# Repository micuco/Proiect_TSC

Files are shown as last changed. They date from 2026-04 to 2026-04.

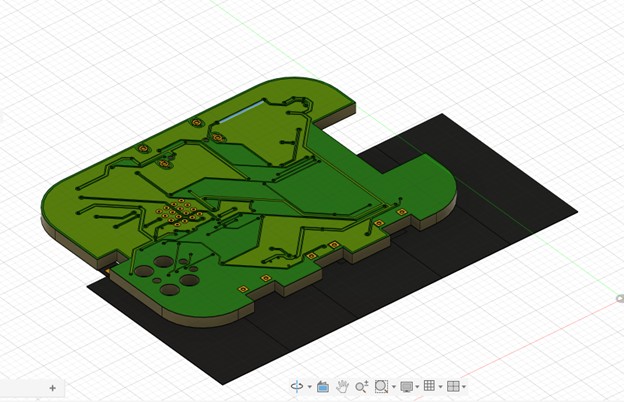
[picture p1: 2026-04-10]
Images/Picture1.jpg

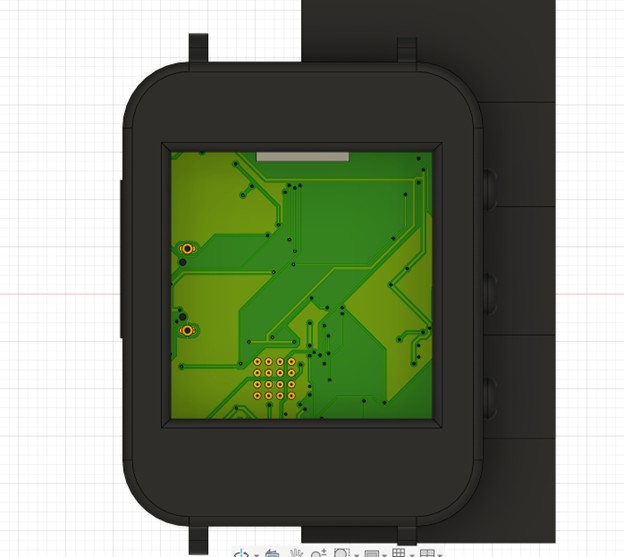
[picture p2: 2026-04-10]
Images/Picture4.jpg

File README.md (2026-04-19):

# Proiect_TSC
InkTime este un smartwatch low-cost, open-source, bazat pe microcontroller-ul nRF52840. Proiectul acopera intreg procesul de dezvoltare hardware, de la schema electrica pana la integrarea mecanica intr-o carcasa.

Sistemul este compus din urmatoarele blocuri principale: MCU nRF52840, Power Management (LiPo Charger + DC/DC), IMU, E-paper Display + Driver, Fuel Gauge, USB-C + ESD Protection, Haptic Driver, Butoane, Interfata SWD.

Microcontroller-ul principal gestioneaza: comunicatia BLE, interfata SPI pentru display, I2C pentru senzori (IMU, fuel gauge),USB pentru alimentare si debug.

Sistemul de alimentare include: BQ25180 pentru incarcarea bateriei LiPo, RT6160 pentru conversie DC/DC, multiple condensatoare de decuplare (100nF, 1uF, 4.7uF). Traseele de alimentare sunt dimensionate conform cerintelor (min 0.3mm).

IMU (BMA421): conectat pe I2C (SDA, SCL), semnale de intrerupere: INT1, INT2, utilizat pentru detectarea miscarii si gesturilor.

E-Paper Display: conectare prin SPI (MOSI, SCK, CS, DC, RST), driver dedicat pentru generarea tensiunilor necesare (boost circuit).

Fuel Gauge: monitorizeaza nivelul bateriei, conectat pe I2C, pin ALERT pentru notificari.

Haptic Driver: DRV2605 pentru control vibratii, control prin I2C, semnal enable din MCU.

USB-C: folosit pentru alimentare si comunicatie, protejat cu circuit ESD dedicat.

Butoane: 3 butoane, conectate la GPIO cu rezistente pull-up/pull-down.

Pin Mapping (nRF52840):

| Functie | Pin |
| --- | --- |
| I2C SDA | P0.xx |
| I2C SCL | P0.xx |
| SPI MOSI | P0.xx |
| SPI SCK | P0.xx |
| EPD CS/DC/RST | GPIO |
| IMU INT | GPIO |
| SWDIO | dedicat |
| SWDCLK | dedicat |

Design Decisions: folosirea e-paper pentru consum redus, integrarea fuel gauge pentru autonomie, antena externa pozitionata la marginea PCB-ului, separarea clara a planurilor de masa.

DRC & ERC: verificari efectuate, respectate regulile de routare, fara unghiuri de 90, condensatoare de decuplare aproape de IC-uri.

PCB Design: PCB 2 layer (TOP + BOTTOM), plan de masa pe ambele layere, via stitching pentru GND, componente plasate pe TOP, trasee: power: ≥ 0.3mm, semnal: ≥ 0.15mm, antena: plasata la marginea PCB, fara plan de masa sub ea.

Modelul 3D include: PCB complet cu componente, baterie LiPo (modelata conform datasheet), display e-paper, carcasa smartwatch.

Integrarea presupune: alinierea butoanelor cu carcasa, pozitionarea corecta a USB-C, fixarea bateriei pe test pads, verificarea spatiului intern si a interferentelor..

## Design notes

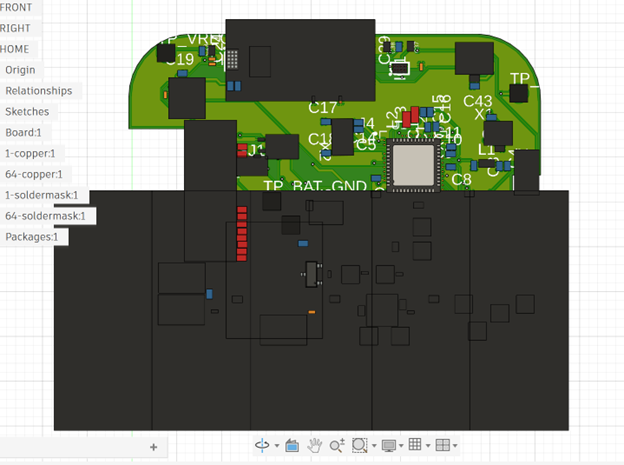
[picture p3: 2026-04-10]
Images/Picture3.png

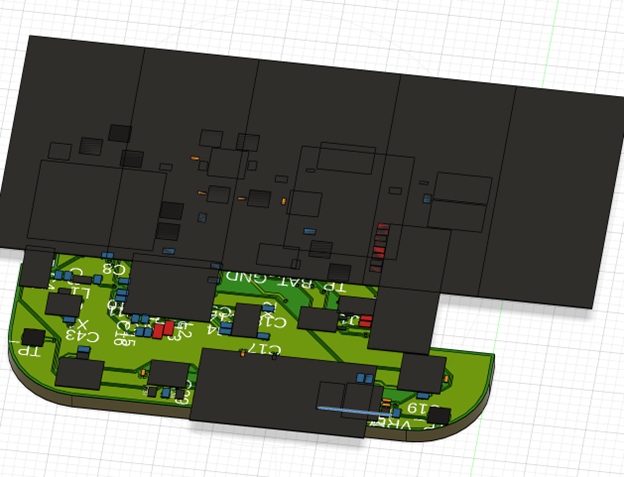
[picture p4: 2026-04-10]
Images/Picture2.png

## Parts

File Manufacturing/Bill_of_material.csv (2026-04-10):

Qty | Value | Device | Package | Parts | Description | ARROW_PART_NUMBER | ARROW_PRICE-STOCK | AVAILABILITY | CHECK_PRICES | COPYRIGHT | DESCRIPTION | DIGI-KEY_PART_NUMBER_1 | DIGI-KEY_PART_NUMBER_2 | DIGI-KEY_PART_NUMBER_3 | HEIGHT | JLCPCB | MANUFACTURER_NAME | MANUFACTURER_PART_NUMBER | MF | MFR_NAME | MOUSER_PART_NUMBER | MOUSER_PRICE-STOCK | MP | PACKAGE | POPULARITY | PRICE | PROD_ID | PURCHASE-URL | SNAPEDA_LINK | TP_SIGNAL_NAME | VALUE
1 |  | ESP32_C6_LIBRARY_7_JUMPER_SJ | ESP32_C6_LIBRARY_7_JUMPER_SJ | SJ1 | SMD solder JUMPER |  |  |  |  |  |  |  |  |  |  |  |  |  |  |  |  |  |  |  | 3
3 | 0 | CPF0201D7K68C1_CPF0201D7K68C1 | CPF0201D7K68C1_0201 | R2, R3, R4 | 7.68k 0201 Thin Film Surface Mount Fixed Resistor +/-0.5% 0.031W CPF0201D7K68C1
4 | 0.1uF | GRM011R60J152KE01L_2_GRM011R60J152KE01L | GRM011R60J152KE01L_2_CAPC0201X13N | C23, C27, C34, C42 | Check availability |  |  | In Stock | https://www.snapeda.com/parts/GRM011R60J152KE01L/Murata/view-part/?ref=eda |  | SMD Capacitor X5R(EIA) with Capacitance: 1500pF Tol. 10%. Rated Voltage: 6.3Vdc |  |  |  |  |  |  |  | Murata |  |  |  | GRM011R60J152KE01L | 0201 Murata |  | None |  |  | https://www.snapeda.com/parts/GRM011R60J152KE01L/Murata/view-part/?ref=snap
1 | 0.1uF/50V | NORDIC_NRF_3_CAPACITOR_0201_L | NORDIC_NRF_3_RESC0201_L | EPD_C5 | Generic chip capacitor
1 | 0.47 | ERA-1AEB3401C_CPF0201D7K68C1 | ERA-1AEB3401C_0201 | R1_EP_DR | 7.68k 0201 Thin Film Surface Mount Fixed Resistor +/-0.5% 0.031W CPF0201D7K68C1
1 | 1.0µF | NORDIC_NRF_3_CAPACITOR_0201_L | NORDIC_NRF_3_RESC0201_L | C15 | Generic chip capacitor
5 | 100nF | NORDIC_NRF_3_CAPACITOR_0201_L | NORDIC_NRF_3_RESC0201_L | C5, C7, C8, C12, C19 | Generic chip capacitor
1 | 100pF | NORDIC_NRF_3_CAPACITOR_0201_L | NORDIC_NRF_3_RESC0201_L | C11 | Generic chip capacitor
5 | 10k | CPF0201D7K68C1_CPF0201D7K68C1 | CPF0201D7K68C1_0201 | R1, R7, R8, R9, R_PWR_EPD | 7.68k 0201 Thin Film Surface Mount Fixed Resistor +/-0.5% 0.031W CPF0201D7K68C1
1 | 10k | ERA-1AEB3401C_CPF0201D7K68C1 | ERA-1AEB3401C_0201 | R2_EP_DR | 7.68k 0201 Thin Film Surface Mount Fixed Resistor +/-0.5% 0.031W CPF0201D7K68C1
3 | 10uF | NORDIC_NRF_3_CAPACITOR_0201_L | NORDIC_NRF_3_RESC0201_L | C1-EP-DR, C24, C39 | Generic chip capacitor
1 | 10µH | NORDIC_NRF_2_INDUCTOR_0402_L | NORDIC_NRF_2_RESC0402_L | L2 | Generic chip inductor
4 | 12pF | NORDIC_NRF_3_CAPACITOR_0201_L | NORDIC_NRF_3_RESC0201_L | C1, C2, C17, C18 | Generic chip capacitor
1 | 15nH | NORDIC_NRF_2_INDUCTOR_0402_L | NORDIC_NRF_2_RESC0402_L | L3 | Generic chip inductor
2 | 1pF | NORDIC_NRF_3_CAPACITOR_0201_L | NORDIC_NRF_3_RESC0201_L | C3, C4 | Generic chip capacitor
6 | 1uF | GRM011R60J152KE01L_2_GRM011R60J152KE01L | GRM011R60J152KE01L_2_CAPC0201X13N | C29, C30, C31, C32, C37, C38 | Check availability |  |  | In Stock | https://www.snapeda.com/parts/GRM011R60J152KE01L/Murata/view-part/?ref=eda |  | SMD Capacitor X5R(EIA) with Capacitance: 1500pF Tol. 10%. Rated Voltage: 6.3Vdc |  |  |  |  |  |  |  | Murata |  |  |  | GRM011R60J152KE01L | 0201 Murata |  | None |  |  | https://www.snapeda.com/parts/GRM011R60J152KE01L/Murata/view-part/?ref=snap
9 | 1uF/50V | NORDIC_NRF_3_CAPACITOR_0201_L | NORDIC_NRF_3_RESC0201_L | EPD_C1, EPD_C2, EPD_C6, EPD_C7, EPD_C8, EPD_C9, EPD_C10, EPD_C11, EPD_C12 | Generic chip capacitor
1 | 2.2 | ERA-1AEB3401C_CPF0201D7K68C1 | ERA-1AEB3401C_0201 | R_TYPE_SEL | 7.68k 0201 Thin Film Surface Mount Fixed Resistor +/-0.5% 0.031W CPF0201D7K68C1
3 | 2025-10-22_07-23-44_LIBRARY_EVP-AKE31ASW_EVP-AKE31A_PAN | 2025-10-22_07-23-44_LIBRARY_EVP-AKE31ASW_EVP-AKE31A_PAN | 2025-10-22_07-23-44_LIBRARY_SW_EVP-AKE31A_PAN | SW_DN, SW_ENT, SW_UP |  |  |  |  |  | Copyright (C) 2025 Ultra Librarian. All rights reserved. |  | P123437TR-ND | P123437CT-ND | P123437DKR-ND |  |  | Panasonic | EVP-AKE31A
1 | 20V/4.2A/52mO/1.4W | ESP32_C6_LIBRARY_4_ESP32_WROVER_SPARKFUN-DISCRETESEMI_MOSFET_PCH-DMG2305UX-7 | ESP32_C6_LIBRARY_4_ESP32_C6_LIBRARY_4_ESP32_C6_LIBRARY_4_ESP32_C6_LIBRARY_4_ESP32_WROVER_SPARKFUN-DISCRETESEMI_SOT23-3 | Q1 | P-channel MOSFETs |  |  |  |  |  |  |  |  |  |  |  |  |  |  |  |  |  |  |  |  |  | TRAN-14388 |  |  |  | 20V/4.2A/52mO/1.4W
2 | 22uF | NORDIC_NRF_3_CAPACITOR_0201_L | NORDIC_NRF_3_RESC0201_L | C25, C33 | Generic chip capacitor
1 | 2450AT18B100E | 2450AT18B100E_2450AT18B100E | 2450AT18B100E_ANTC3216X140N | ANT1 | Antennas 2.45GHz ANTENNA | 2450AT18B100E | https://www.arrow.com/en/products/2450at18b100e/johanson-dielectrics?utm_currency=USD&region=nac |  |  |  | Antennas 2.45GHz ANTENNA |  |  |  | 1.4mm |  | JOHANSON TECHNOLOGY | 2450AT18B100E |  |  | 609-2450AT18B100E | https://www.mouser.co.uk/ProductDetail/Johanson-Technology/2450AT18B100E?qs=yCnrNFeXz%252Bh5MFsFIXGZGA%3D%3D
1 | 3.9nH | NORDIC_NRF_2_INDUCTOR_0402_L | NORDIC_NRF_2_RESC0402_L | L1 | Generic chip inductor
1 | 32.768kHz | NORDIC_NRF_1_XTAL_32KHZ | NORDIC_NRF_1_XTAL_3215_N | X2
1 | 32MHz | NORDIC_NRF_XTAL_32MHZ | NORDIC_NRF_BT-XTAL_2016_N | X1
2 | 3K3 | CPF0201D7K68C1_CPF0201D7K68C1 | CPF0201D7K68C1_0201 | R17, R18 | 7.68k 0201 Thin Film Surface Mount Fixed Resistor +/-0.5% 0.031W CPF0201D7K68C1
1 | 4.7uF | NORDIC_NRF_3_CAPACITOR_0201_L | NORDIC_NRF_3_RESC0201_L | C43 | Generic chip capacitor
1 | 4.7uF/25V | NORDIC_NRF_3_CAPACITOR_0201_L | NORDIC_NRF_3_RESC0201_L | C2-EP-DR | Generic chip capacitor
4 | 4.7µF | NORDIC_NRF_3_CAPACITOR_0201_L | NORDIC_NRF_3_RESC0201_L | C6, C14, C20, C21 | Generic chip capacitor
1 | 47nF | NORDIC_NRF_3_CAPACITOR_0201_L | NORDIC_NRF_3_RESC0201_L | C16 | Generic chip capacitor
1 | 503480-2400 | 503480-2400_503480-2400 | 503480-2400_5034802400 | J1 | FFC & FPC Connectors 0.5mm FPC RA SMT Dual Contact 24Ckt |  |  |  |  |  | FFC & FPC Connectors 0.5mm FPC RA SMT Dual Contact 24Ckt |  |  |  | 1.87mm |  | Molex | 503480-2400 |  |  | 538-503480-2400 | https://www.mouser.co.uk/ProductDetail/Molex/503480-2400?qs=OAhjpuo3Vu7efIoxFh9AOw%3D%3D
1 | 5K1 | CPF0201D7K68C1_CPF0201D7K68C1 | CPF0201D7K68C1_0201 | R1_USB | 7.68k 0201 Thin Film Surface Mount Fixed Resistor +/-0.5% 0.031W CPF0201D7K68C1
1 | 5K1 | ERA-1AEB3401C_CPF0201D7K68C1 | ERA-1AEB3401C_0201 | R2_USB | 7.68k 0201 Thin Film Surface Mount Fixed Resistor +/-0.5% 0.031W CPF0201D7K68C1
1 | 68uH | ESP32_C6_LIBRARY_2_744043680IND_4828-WE-TPC_WRE | ESP32_C6_LIBRARY_2_IND_4828-WE-TPC_WRE | L5 |  |  |  |  |  | Copyright (C) 2024 Ultra Librarian. All rights reserved. |  |  |  |  |  |  |  | 744043680 |  | Wurth Electronics
1 | 820pF | NORDIC_NRF_3_CAPACITOR_0201_L | NORDIC_NRF_3_RESC0201_L | C9 | Generic chip capacitor
1 | BMA421 | BMA423_BMA423 | BMA423_BMA423 | IC3 | Accelerometers Triaxial low-g 12bit Acceleration Sensor | BMA423 | https://www.arrow.com/en/products/bma423/bosch |  |  |  | Accelerometers Triaxial low-g 12bit Acceleration Sensor |  |  |  | 1mm |  | BOSCH | BMA423 |  |  | 262-BMA423 | https://www.mouser.co.uk/ProductDetail/Bosch-Sensortec/BMA423?qs=HXFqYaX1Q2xC%252BSgeGoX3mg%3D%3D
1 | BQ25180YBGR | BQ25180YBGR_BQ25180YBGR | BQ25180YBGR_BGA8C40P2X4_100X155X50 | IC1 | Charger IC Lithium Ion/Polymer, Lithium Iron Phosphate 8-DSBGA (1.6x1.1) | BQ25180YBGR | https://www.arrow.com/en/products/bq25180ybgr/texas-instruments?utm_currency=USD&region=nac |  |  |  | Charger IC Lithium Ion/Polymer | Lithium Iron Phosphate 8-DSBGA (1.6x1.1) |  |  |  | 0.5mm |  | Texas Instruments | BQ25180YBGR |  |  | 595-BQ25180YBGR | https://www.mouser.co.uk/ProductDetail/Texas-Instruments/BQ25180YBGR?qs=doiCPypUmgEWjAK%252BJAX6Tw%3D%3D
1 | DRV2605YZFR | DRV2605YZFR_DRV2605YZFR | DRV2605YZFR_BGA9C50P3X3_144X144X62 | IC2 | Haptic Driver for ERM/LRA with Built-In Library and Smart Loop Architecture | DRV2605YZFR | https://www.arrow.com/en/products/drv2605yzfr/texas-instruments?region=nac |  |  |  | Haptic Driver for ERM/LRA with Built-In Library and Smart Loop Architecture |  |  |  | 0.625mm |  | Texas Instruments | DRV2605YZFR
1 | FTC252012SR47MBCA | MLP2016SR47MT0S1_FTC252012SR47MBCA | MLP2016SR47MT0S1_INDC2016X100N | L7 | SMD / SMT Inductors (Coils), L=0.47?H, L x W x T : |  |  |  |  |  | SMD / SMT Inductors (Coils) | L=0.47?H | L x W x T : |  |  |  | 1mm | https://jlcpcb.com/partdetail/6763488-FTC252012SR47MBCA/C5832368 | TDK | FTC252012SR47MBCA
14 | HECTOR_WATCH_1_TPTP20R | HECTOR_WATCH_1_TPTP20R | HECTOR_WATCH_1_TP20R | TP_3.3V, TP_3V3, TP_BAT_GND, TP_GND, TP_ON, TP_OP, TP_RESET, TP_SCL, TP_SDA, TP_SWDCLK, TP_SWDIO, TP_SWO, TP_VBAT, TP_VREG | Test pad |  |  |  |  |  |  |  |  |  |  |  |  |  |  |  |  |  |  |  | 2
1 | KH-TYPE-C-16P | KH-TYPE-C-16P_KH-TYPE-C-16P | KH-TYPE-C-16P_KINGHELM_KH-TYPE-C-16P | J4 | Check availability |  |  | Not in stock | https://www.snapeda.com/parts/KH-TYPE-C-16P/Kinghelm/view-part/?ref=eda |  |  |  |  |  |  |  |  |  | kinghelm |  |  |  | KH-TYPE-C-16P | None |  | None |  |  | https://www.snapeda.com/parts/KH-TYPE-C-16P/Kinghelm/view-part/?ref=snap
1 | MAX17048G+T10 | ESP32_C6_LIBRARY_MAX17048G+T10 | ESP32_C6_LIBRARY_SON50P200X200X80-9N | U3 | Check availability |  |  | In Stock | https://www.snapeda.com/parts/MAX17048G+T10/Analog+Devices/view-part/?ref=eda |  | 3µA 1-Cell/2-Cell Fuel Gauge with ModelGauge |  |  |  |  |  |  |  | Analog Devices |  |  |  | MAX17048G+T10 | TDFN-8 Maxim |  | None |  | https://www.snapeda.com/api/url_track_click_mouser/?unipart_id=329239&manufacturer=Analog Devices&part_name=MAX17048G+T10&search_term=None | https://www.snapeda.com/parts/MAX17048G+T10/Analog+Devices/view-part/?ref=snap
3 | MBR0530 | ESP32_C6_LIBRARY_5_MBR0530 | ESP32_C6_LIBRARY_5_SOD3716X135N | D2, D4, D5 | ON SEMICONDUCTOR - MBR0530 - DIODE, SCHOTTKY, 0.5A, 30V, SOD-123 |  |  | In Stock | https://www.snapeda.com/parts/MBR0530/Onsemi/view-part/?ref=eda |  | Diode Schottky 30 V 500mA Surface Mount SOD-123 |  |  |  |  |  |  |  | ON Semiconductor |  |  |  | MBR0530 | SOD-123-2 ON Semiconductor |  | None |  | https://www.snapeda.com/api/url_track_click_mouser/?unipart_id=179458&manufacturer=ON Semiconductor&part_name=MBR0530&search_term=None | https://www.snapeda.com/parts/MBR0530/Onsemi/view-part/?ref=snap
3 | N.C. | NORDIC_NRF_3_CAPACITOR_0201_L | NORDIC_NRF_3_RESC0201_L | C10, C13, C22 | Generic chip capacitor
1 | NRF52840_QF | NORDIC_NRF_4_NRF52840_QF | NORDIC_NRF_4_AQFN50P700X700X85_HS-74N | U1 | nRF52840
1 | RT6160AWSC | RT6160AWSC_RT6160AWSC | RT6160AWSC_BGA15C40P3X5_140X230X60 | IC9 | Buck-Boost Regulator Positive Output Step-Up/Step-Down I2C DC-DC Controller IC 15-WL-CSP (BSC) (1.4x2.3) |  |  |  |  |  | Buck-Boost Regulator Positive Output Step-Up/Step-Down I2C DC-DC Controller IC 15-WL-CSP (BSC) (1.4x2.3) |  |  |  | 0.6mm |  | RICHTEK | RT6160AWSC |  |  | 835-RT6160AWSC | https://www.mouser.co.uk/ProductDetail/Richtek/RT6160AWSC?qs=amGC7iS6iy%2FLd9PSoixZXQ%3D%3D
1 | SI1308EDL-T1-GE3 | ESP32_C6_LIBRARY_6_SI1308EDL-T1-GE3 | ESP32_C6_LIBRARY_6_SOT65P210X110-3N | Q3 | MOSFET N-Ch 30V 1.5A TrenchFET SC70 Vishay Si1308EDL-T1-GE3 N-channel MOSFET Transistor, 1.5 A, 30 V, 3-Pin SC-70 |  |  | In Stock | https://www.snapeda.com/parts/SI1308EDL-T1-GE3/Vishay+Siliconix/view-part/?ref=eda |  | Si1308EDL-T1-GE3 N-channel MOSFET Transistor | 1.5 A | 30 V | 3-Pin SC-70 | Siliconix / Vishay SI1308EDL-T1-GE3 |  |  |  |  |  |  |  | Vishay Siliconix |  |  |  | SI1308EDL-T1-GE3 | SOT-323 Vishay Semiconductor |  | None |  | https://www.snapeda.com/api/url_track_click_mouser/?unipart_id=274603&manufacturer=Vishay Siliconix&part_name=SI1308EDL-T1-GE3&search_term=None
1 | TC2030-IDC | TC2030-IDC_TC2030-IDC | TC2030-IDC_TC2030IDC | J2 | CABLE ADAPTER 6 POS |  |  |  |  |  | CABLE ADAPTER 6 POS |  |  |  | 19mm |  | Tag Connect | TC2030-IDC
1 | USBLC6-2SC6Y | ESP32_C6_LIBRARY_3_USBLC6-2SC6Y | ESP32_C6_LIBRARY_3_SOT95P280X145-6N | D3 | Low Cap. ESD Protection Auto SOT-23-6 STMicroelectronics USBLC6-2SC6Y, Dual Uni-Directional TVS Diode Array, 6-Pin SOT-23 |  |  | In Stock | https://www.snapeda.com/parts/USBLC6-2SC6Y/STMicroelectronics/view-part/?ref=eda |  | 17V Clamp 5A (8/20µs) Ipp Tvs Diode Surface Mount SOT-23-6 |  |  |  |  |  |  |  | STMicroelectronics |  |  |  | USBLC6-2SC6Y | SOT-23-6 STMicroelectronics |  | None |  |  | https://www.snapeda.com/parts/USBLC6-2SC6Y/STMicroelectronics/view-part/?ref=snap

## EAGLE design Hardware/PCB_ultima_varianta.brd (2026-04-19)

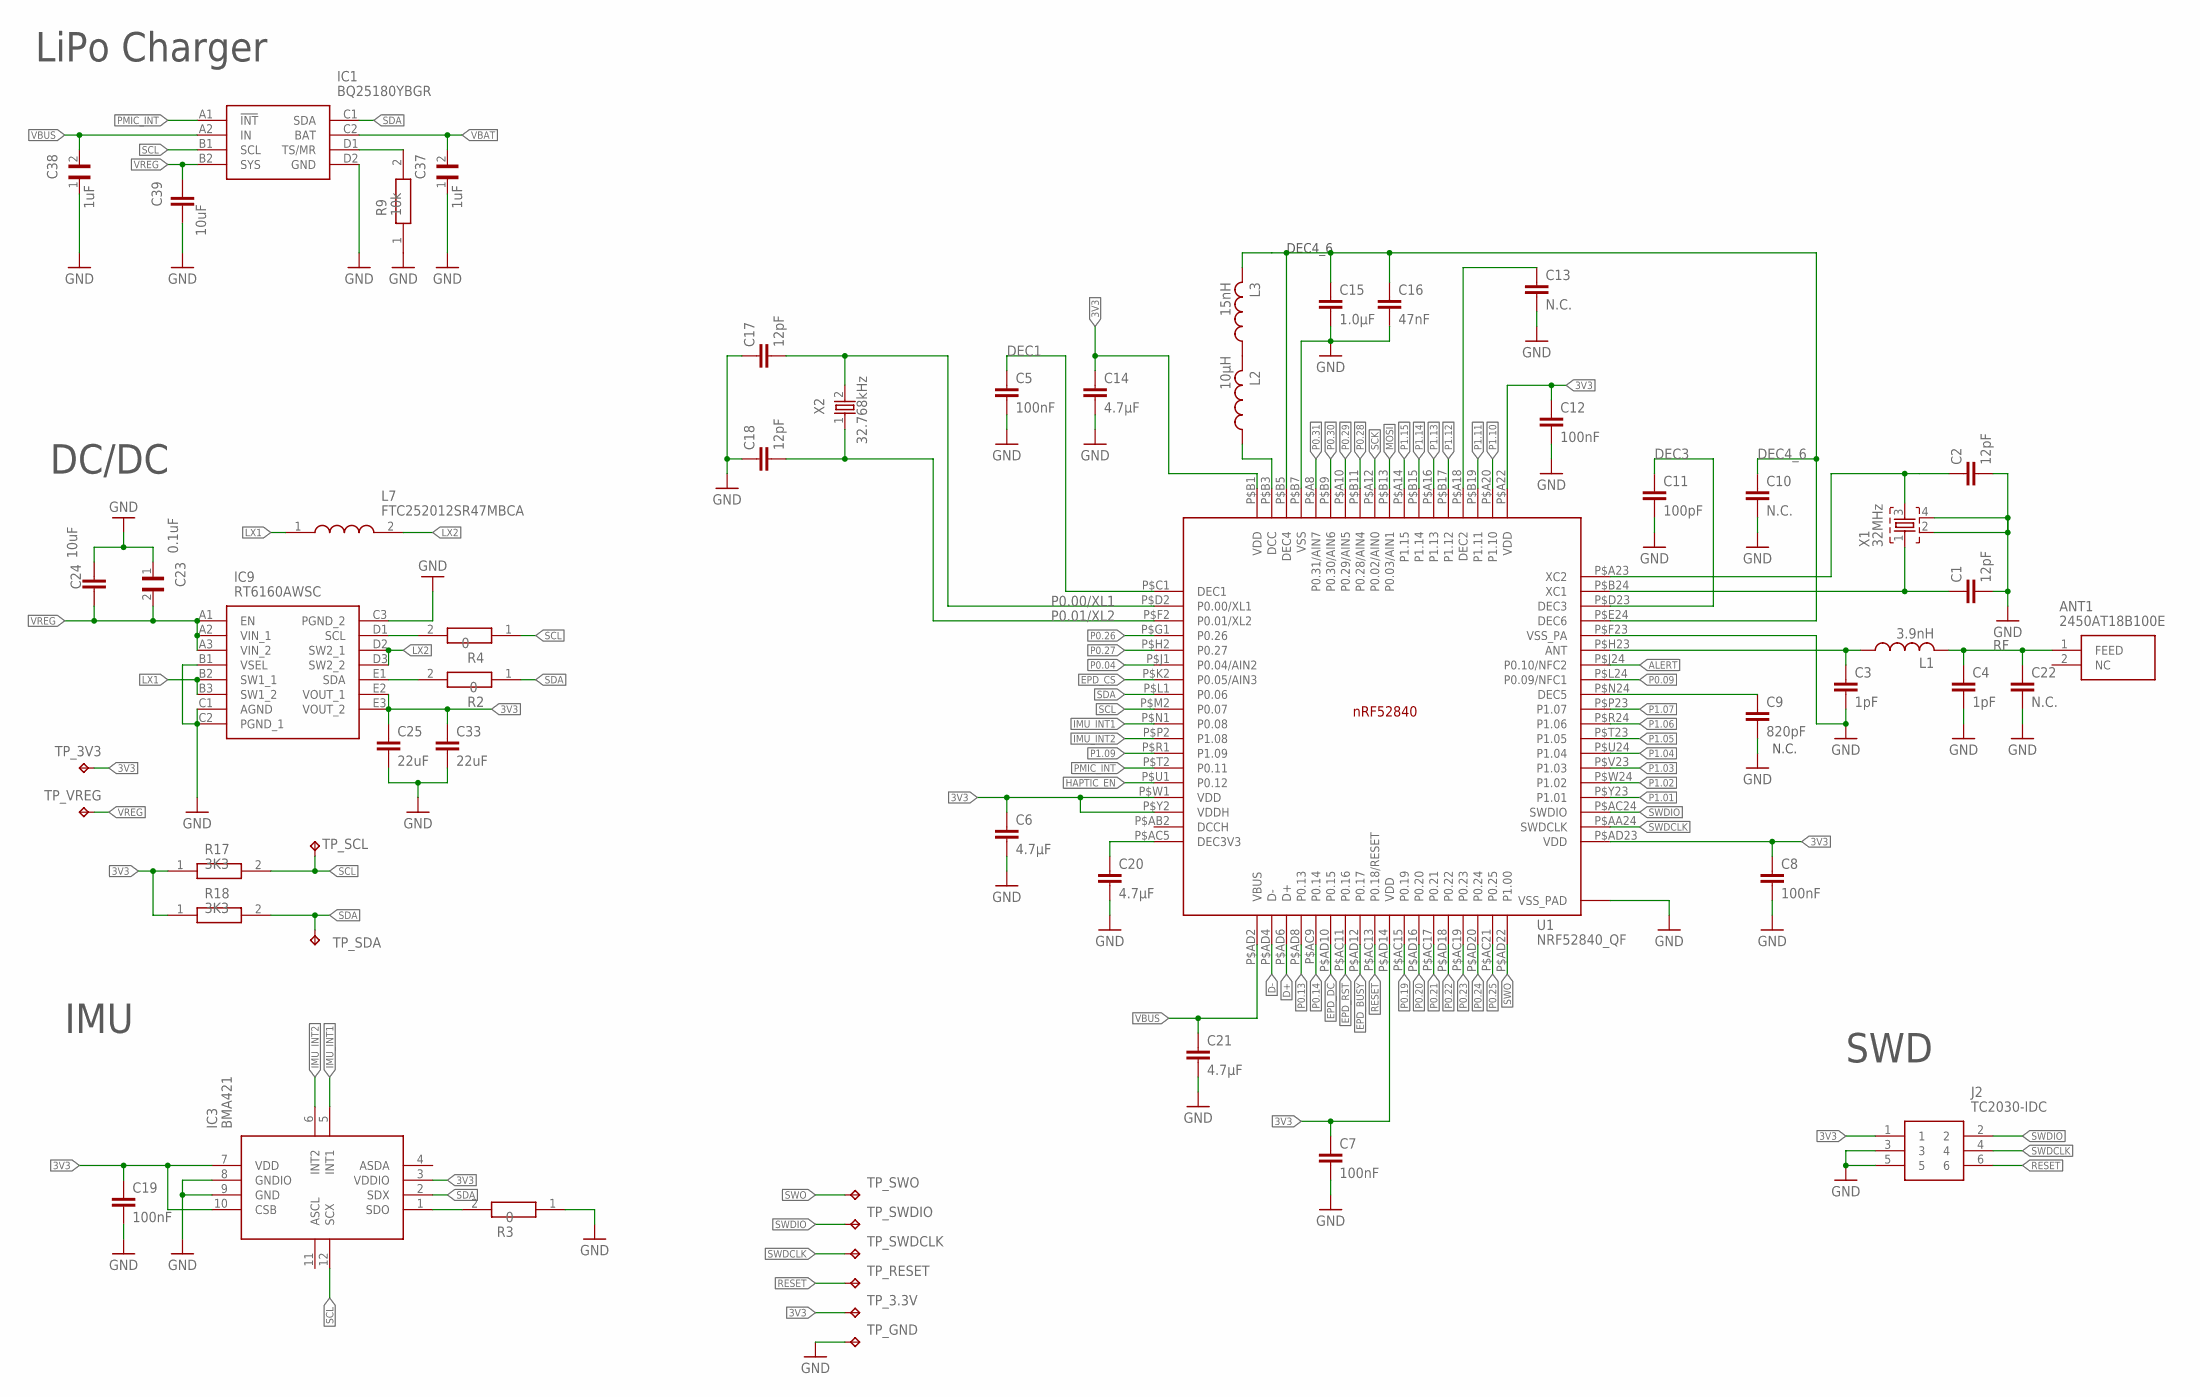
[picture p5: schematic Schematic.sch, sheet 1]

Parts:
ANT1: 2450AT18B100E; 2450AT18B100E_ANTC3216X140N
C1, C2, C17, C18: 12pF; NORDIC_NRF_3_RESC0201_L
C3, C4: 1pF; NORDIC_NRF_3_RESC0201_L
C5, C7, C8, C12, C19: 100nF; NORDIC_NRF_3_RESC0201_L
C6, C14, C20, C21: 4.7µF; NORDIC_NRF_3_RESC0201_L
C9: 820pF; NORDIC_NRF_3_RESC0201_L
C10, C13, C22: N.C.; NORDIC_NRF_3_RESC0201_L
C11: 100pF; NORDIC_NRF_3_RESC0201_L
C15: 1.0µF; NORDIC_NRF_3_RESC0201_L
C16: 47nF; NORDIC_NRF_3_RESC0201_L
C23: 0.1uF; GRM011R60J152KE01L_2_CAPC0201X13N
C24, C39: 10uF; NORDIC_NRF_3_RESC0201_L
C25, C33: 22uF; NORDIC_NRF_3_RESC0201_L
C37, C38: 1uF; GRM011R60J152KE01L_2_CAPC0201X13N
IC1: BQ25180YBGR; BQ25180YBGR_BGA8C40P2X4_100X155X50
IC3: BMA421; BMA423_BMA423
IC9: RT6160AWSC; RT6160AWSC_BGA15C40P3X5_140X230X60
J2: TC2030-IDC; TC2030-IDC_TC2030IDC
L1: 3.9nH; NORDIC_NRF_2_RESC0402_L
L2: 10µH; NORDIC_NRF_2_RESC0402_L
L3: 15nH; NORDIC_NRF_2_RESC0402_L
L7: FTC252012SR47MBCA; MLP2016SR47MT0S1_INDC2016X100N
R2, R3, R4: 0; CPF0201D7K68C1_0201
R9: 10k; CPF0201D7K68C1_0201
R17, R18: 3K3; CPF0201D7K68C1_0201
TP_3.3V, TP_3V3: HECTOR_WATCH_1_TPTP20R; HECTOR_WATCH_1_TP20R
TP_GND: HECTOR_WATCH_1_TPTP20R; HECTOR_WATCH_1_TP20R
TP_RESET: HECTOR_WATCH_1_TPTP20R; HECTOR_WATCH_1_TP20R
TP_SCL: HECTOR_WATCH_1_TPTP20R; HECTOR_WATCH_1_TP20R
TP_SDA: HECTOR_WATCH_1_TPTP20R; HECTOR_WATCH_1_TP20R
TP_SWDCLK: HECTOR_WATCH_1_TPTP20R; HECTOR_WATCH_1_TP20R
TP_SWDIO: HECTOR_WATCH_1_TPTP20R; HECTOR_WATCH_1_TP20R
TP_SWO: HECTOR_WATCH_1_TPTP20R; HECTOR_WATCH_1_TP20R
TP_VREG: HECTOR_WATCH_1_TPTP20R; HECTOR_WATCH_1_TP20R
U1: NRF52840_QF; NORDIC_NRF_4_AQFN50P700X700X85_HS-74N
X1: 32MHz; NORDIC_NRF_BT-XTAL_2016_N
X2: 32.768kHz; NORDIC_NRF_1_XTAL_3215_N

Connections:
3V3: C6.1, C7.1, C8.1, C12.1, C14.1, C19.1, C25.1, C33.1, IC3.3 (VDDIO), IC3.7 (VDD), IC3.10 (CSB), IC9.E2 (VOUT_1), IC9.E3 (VOUT_2), J2.1, R17.1, R18.1, TP_3.3V.TP, TP_3V3.TP, U1.P$A22 (VDD), U1.P$AD14 (VDD), U1.P$AD23 (VDD), U1.P$B1 (VDD), U1.P$W1 (VDD), U1.P$Y2 (VDDH); also elsewhere on the board
ALERT: U1.P$J24 (P0.10/NFC2); also elsewhere on the board
D+: U1.P$AD6 (D+); also elsewhere on the board
D-: U1.P$AD4 (D-); also elsewhere on the board
DEC1: C5.1, U1.P$C1 (DEC1)
DEC3: C11.1, U1.P$D23 (DEC3)
DEC4_6: C10.1, C15.1, C16.1, L3.2, U1.P$B5 (DEC4), U1.P$E24 (DEC6)
EPD_BUSY: U1.P$AD12 (P0.17); also elsewhere on the board
EPD_CS: U1.P$K2 (P0.05/AIN3); also elsewhere on the board
EPD_DC: U1.P$AD10 (P0.15); also elsewhere on the board
EPD_RST: U1.P$AC11 (P0.16); also elsewhere on the board
GND: C1.2, C2.2, C3.2, C4.2, C5.2, C6.2, C7.2, C8.2, C9.2, C10.2, C11.2, C12.2, C13.2, C14.2, C15.2, C16.2, C17.1, C18.1, C19.2, C20.2, C21.2, C22.2, C23.1, C24.2, C25.2, C33.2, C37.1, C38.1, C39.2, IC1.D2 (GND), IC3.8 (GNDIO), IC3.9 (GND), IC9.B1 (VSEL), IC9.C1 (AGND), IC9.C2 (PGND_1), IC9.C3 (PGND_2), J2.3, J2.5, R3.1, R9.1, TP_GND.TP, U1.P$74 (VSS_PAD), U1.P$75 (VSS_PAD), U1.P$76 (VSS_PAD), U1.P$77 (VSS_PAD), U1.P$78 (VSS_PAD), U1.P$79 (VSS_PAD), U1.P$80 (VSS_PAD), U1.P$81 (VSS_PAD), U1.P$82 (VSS_PAD), U1.P$83 (VSS_PAD), U1.P$84 (VSS_PAD), U1.P$85 (VSS_PAD), U1.P$86 (VSS_PAD), U1.P$87 (VSS_PAD), U1.P$88 (VSS_PAD), U1.P$89 (VSS_PAD), U1.P$90 (VSS_PAD), U1.P$B7 (VSS), U1.P$F23 (VSS_PA), X1.2, X1.4; also elsewhere on the board
HAPTIC_EN: U1.P$U1 (P0.12); also elsewhere on the board
IMU_INT1: IC3.5 (INT1), U1.P$N1 (P0.08)
IMU_INT2: IC3.6 (INT2), U1.P$P2 (P1.08)
LX1: IC9.B2 (SW1_1), IC9.B3 (SW1_2), L7.1
LX2: IC9.D2 (SW2_1), IC9.D3 (SW2_2), L7.2
MOSI: U1.P$B13 (P0.03/AIN1); also elsewhere on the board
unnamed: IC1.D1 (TS/MR), R9.2
unnamed: IC3.1 (SDO), R3.2
unnamed: C13.1, U1.P$A18 (DEC2)
unnamed: IC9.D1 (SCL), R4.2
unnamed: IC9.E1 (SDA), R2.2
unnamed: C9.1, U1.P$N24 (DEC5)
unnamed: C20.1, U1.P$AC5 (DEC3V3)
unnamed: L2.2, L3.1
unnamed: L2.1, U1.P$B3 (DCC)
unnamed: C3.1, L1.1, U1.P$H23 (ANT)
unnamed: C1.1, U1.P$B24 (XC1), X1.1
unnamed: C2.1, U1.P$A23 (XC2), X1.3
P0.00/XL1: C17.2, U1.P$D2 (P0.00/XL1), X2.2
P0.01/XL2: C18.2, U1.P$F2 (P0.01/XL2), X2.1
P0.04: U1.P$J1 (P0.04/AIN2)
P0.09: U1.P$L24 (P0.09/NFC1)
P0.13: U1.P$AD8 (P0.13); also elsewhere on the board
P0.14: U1.P$AC9 (P0.14); also elsewhere on the board
P0.19: U1.P$AC15 (P0.19)
P0.20: U1.P$AD16 (P0.20)
P0.21: U1.P$AC17 (P0.21)
P0.22: U1.P$AD18 (P0.22)
P0.23: U1.P$AC19 (P0.23)
P0.24: U1.P$AD20 (P0.24)
P0.25: U1.P$AC21 (P0.25)
P0.26: U1.P$G1 (P0.26)
P0.27: U1.P$H2 (P0.27)
P0.28: U1.P$B11 (P0.28/AIN4)
P0.29: U1.P$A10 (P0.29/AIN5)
P0.30: U1.P$B9 (P0.30/AIN6)
P0.31: U1.P$A8 (P0.31/AIN7)
P1.01: U1.P$Y23 (P1.01); also elsewhere on the board
P1.02: U1.P$W24 (P1.02); also elsewhere on the board
P1.03: U1.P$V23 (P1.03)
P1.04: U1.P$U24 (P1.04)
P1.05: U1.P$T23 (P1.05)
P1.06: U1.P$R24 (P1.06)
P1.07: U1.P$P23 (P1.07)
P1.09: U1.P$R1 (P1.09)
P1.10: U1.P$A20 (P1.10)
P1.11: U1.P$B19 (P1.11)
P1.12: U1.P$B17 (P1.12)
P1.13: U1.P$A16 (P1.13)
P1.14: U1.P$B15 (P1.14)
P1.15: U1.P$A14 (P1.15)
PMIC_INT: IC1.A1 (!INT), U1.P$T2 (P0.11)
RESET: J2.6, TP_RESET.TP, U1.P$AC13 (P0.18/RESET)
RF: ANT1.1 (FEED), C4.1, C22.1, L1.2
SCK: U1.P$A12 (P0.02/AIN0); also elsewhere on the board
SCL: IC1.B1 (SCL), IC3.12 (SCX), R4.1, R17.2, TP_SCL.TP, U1.P$M2 (P0.07); also elsewhere on the board
SDA: IC1.C1 (SDA), IC3.2 (SDX), R2.1, R18.2, TP_SDA.TP, U1.P$L1 (P0.06); also elsewhere on the board
SWDCLK: J2.4, TP_SWDCLK.TP, U1.P$AA24 (SWDCLK)
SWDIO: J2.2, TP_SWDIO.TP, U1.P$AC24 (SWDIO)
SWO: TP_SWO.TP, U1.P$AD22 (P1.00)
VBAT: C37.2, IC1.C2 (BAT); also elsewhere on the board
VBUS: C21.1, C38.2, IC1.A2 (IN), U1.P$AD2 (VBUS); also elsewhere on the board
VREG: C23.2, C24.1, C39.1, IC1.B2 (SYS), IC9.A1 (EN), IC9.A2 (VIN_1), IC9.A3 (VIN_2), TP_VREG.TP

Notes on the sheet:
LiPo Charger
DC/DC
IMU
SWD
N.C.
DEC4_6

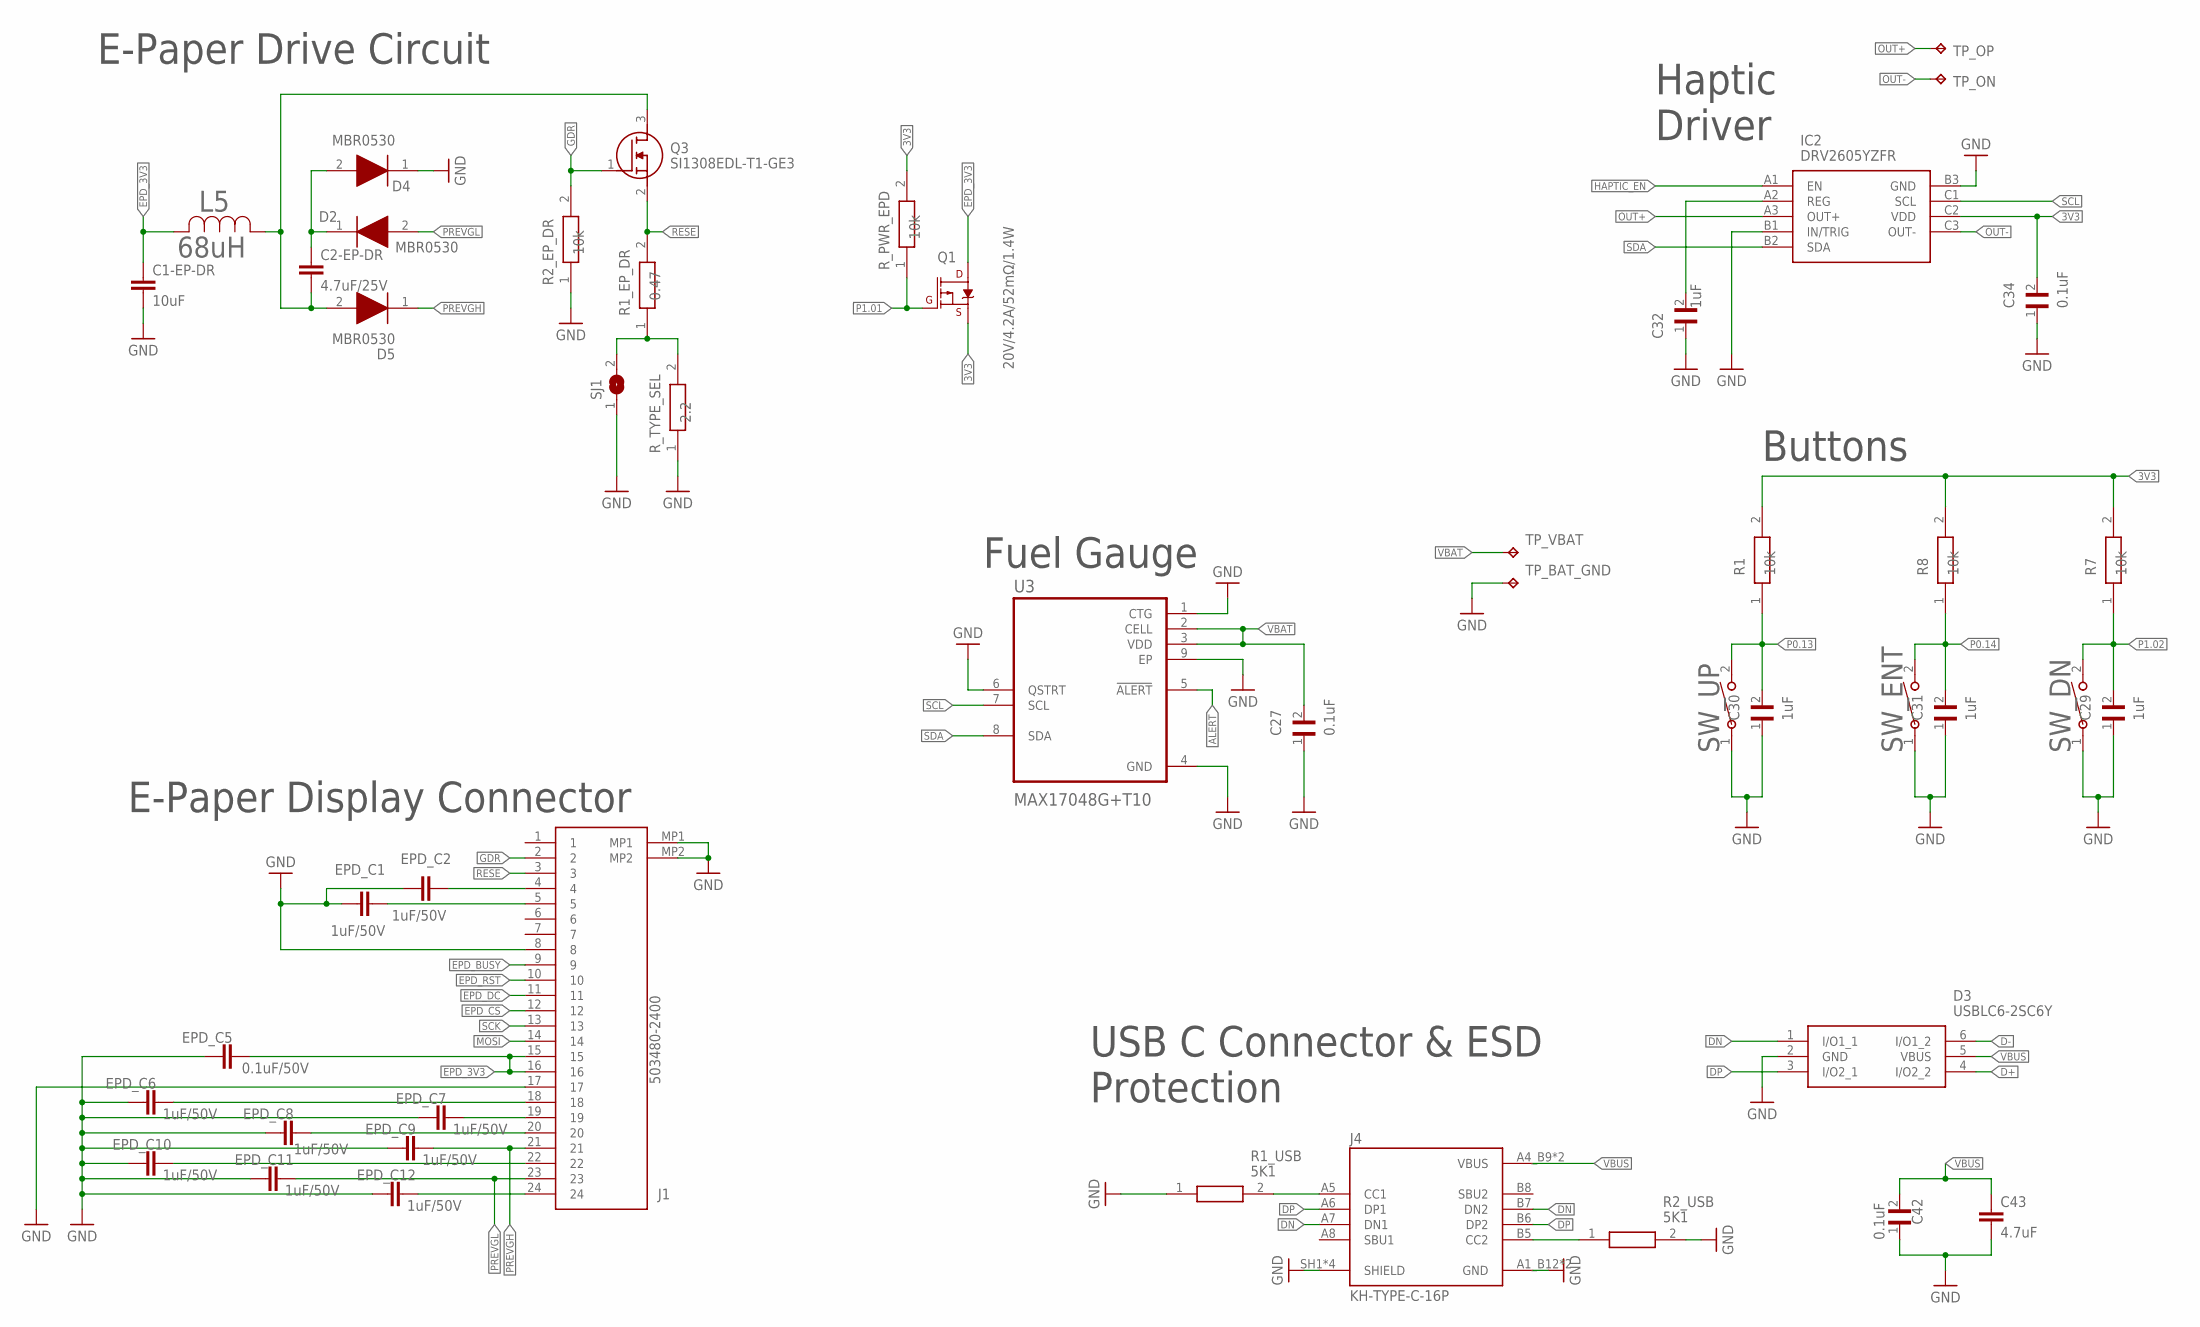
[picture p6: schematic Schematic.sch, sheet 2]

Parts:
C1-EP-DR: 10uF; NORDIC_NRF_3_RESC0201_L
C2-EP-DR: 4.7uF/25V; NORDIC_NRF_3_RESC0201_L
C27, C34, C42: 0.1uF; GRM011R60J152KE01L_2_CAPC0201X13N
C29, C30, C31, C32: 1uF; GRM011R60J152KE01L_2_CAPC0201X13N
C43: 4.7uF; NORDIC_NRF_3_RESC0201_L
D2, D4, D5: MBR0530; ESP32_C6_LIBRARY_5_SOD3716X135N
D3: USBLC6-2SC6Y; ESP32_C6_LIBRARY_3_SOT95P280X145-6N
EPD_C1, EPD_C2, EPD_C6, EPD_C7, EPD_C8, EPD_C9, EPD_C10, EPD_C11, EPD_C12: 1uF/50V; NORDIC_NRF_3_RESC0201_L
EPD_C5: 0.1uF/50V; NORDIC_NRF_3_RESC0201_L
IC2: DRV2605YZFR; DRV2605YZFR_BGA9C50P3X3_144X144X62
J1: 503480-2400; 503480-2400_5034802400
J4: KH-TYPE-C-16P; KH-TYPE-C-16P_KINGHELM_KH-TYPE-C-16P
L5: 68uH; ESP32_C6_LIBRARY_2_IND_4828-WE-TPC_WRE
Q1: 20V/4.2A/52mΩ/1.4W; ESP32_C6_LIBRARY_4_ESP32_C6_LIBRARY_4_ESP32_C6_LIBRARY_4_ES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
Q3: SI1308EDL-T1-GE3; ESP32_C6_LIBRARY_6_SOT65P210X110-3N
R1, R7, R8: 10k; CPF0201D7K68C1_0201
R1_EP_DR: 0.47; ERA-1AEB3401C_0201
R1_USB: 5K1; CPF0201D7K68C1_0201
R2_EP_DR: 10k; ERA-1AEB3401C_0201
R2_USB: 5K1; ERA-1AEB3401C_0201
R_PWR_EPD: 10k; CPF0201D7K68C1_0201
R_TYPE_SEL: 2.2; ERA-1AEB3401C_0201
SJ1: ESP32_C6_LIBRARY_7_JUMPER_SJ
SW_DN: 2025-10-22_07-23-44_LIBRARY_EVP-AKE31ASW_EVP-AKE3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; 2025-10-22_07-23-44_LIBRARY_SW_EVP-AKE31A_PAN
SW_ENT: 2025-10-22_07-23-44_LIBRARY_EVP-AKE31ASW_EVP-AKE3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; 2025-10-22_07-23-44_LIBRARY_SW_EVP-AKE31A_PAN
SW_UP: 2025-10-22_07-23-44_LIBRARY_EVP-AKE31ASW_EVP-AKE3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; 2025-10-22_07-23-44_LIBRARY_SW_EVP-AKE31A_PAN
TP_BAT_GND: HECTOR_WATCH_1_TPTP20R; HECTOR_WATCH_1_TP20R
TP_ON: HECTOR_WATCH_1_TPTP20R; HECTOR_WATCH_1_TP20R
TP_OP: HECTOR_WATCH_1_TPTP20R; HECTOR_WATCH_1_TP20R
TP_VBAT: HECTOR_WATCH_1_TPTP20R; HECTOR_WATCH_1_TP20R
U3: MAX17048G+T10; ESP32_C6_LIBRARY_SON50P200X200X80-9N

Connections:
3V3: C34.2, IC2.C2 (VDD), Q1.2 (S), R1.2, R7.2, R8.2, R_PWR_EPD.2; also elsewhere on the board
ALERT: U3.5 (!ALERT); also elsewhere on the board
D+: D3.4 (I/O2_2); also elsewhere on the board
D-: D3.6 (I/O1_2); also elsewhere on the board
DN: D3.1 (I/O1_1), J4.A7 (DN1), J4.B7 (DN2)
DP: D3.3 (I/O2_1), J4.A6 (DP1), J4.B6 (DP2)
EPD_3V3: C1-EP-DR.1, EPD_C5.2, J1.15, J1.16, L5.2, Q1.3 (D)
EPD_BUSY: J1.9; also elsewhere on the board
EPD_CS: J1.12; also elsewhere on the board
EPD_DC: J1.11; also elsewhere on the board
EPD_RST: J1.10; also elsewhere on the board
GDR: J1.2, Q3.1 (G), R2_EP_DR.2
GND: C1-EP-DR.2, C27.1, C29.1, C30.1, C31.1, C32.1, C34.1, C42.1, C43.2, D3.2 (GND), D4.1 (K), EPD_C1.1, EPD_C2.1, EPD_C5.1, EPD_C6.1, EPD_C7.1, EPD_C8.1, EPD_C9.1, EPD_C10.1, EPD_C11.1, EPD_C12.1, IC2.B1 (IN/TRIG), IC2.B3 (GND), J1.8, J1.17, J1.MP1, J1.MP2, J4.A1_B12 (GND), J4.A12_B1 (GND), J4.SH1 (SHIELD), J4.SH2 (SHIELD), J4.SH3 (SHIELD), J4.SH4 (SHIELD), R1_USB.1, R2_EP_DR.1, R2_USB.2, R_TYPE_SEL.1, SJ1.1, SW_DN.1, SW_ENT.1, SW_UP.1, TP_BAT_GND.TP, U3.1 (CTG), U3.4 (GND), U3.6 (QSTRT), U3.9 (EP); also elsewhere on the board
HAPTIC_EN: IC2.A1 (EN); also elsewhere on the board
MOSI: J1.14; also elsewhere on the board
unnamed: C32.2, IC2.A2 (REG)
unnamed: EPD_C2.2, J1.4
unnamed: C2-EP-DR.2, D5.2 (A), L5.1, Q3.3 (D)
unnamed: C2-EP-DR.1, D2.1 (K), D4.2 (A)
unnamed: R1_EP_DR.1, R_TYPE_SEL.2, SJ1.2
unnamed: EPD_C1.2, J1.5
unnamed: J4.B5 (CC2), R2_USB.1
unnamed: EPD_C6.2, J1.18
unnamed: EPD_C7.2, J1.19
unnamed: EPD_C8.2, J1.20
unnamed: EPD_C10.2, J1.22
unnamed: J4.A5 (CC1), R1_USB.2
unnamed: EPD_C12.2, J1.24
OUT+: IC2.A3 (OUT+), TP_OP.TP
OUT-: IC2.C3 (OUT-), TP_ON.TP
P0.13: C30.2, R1.1, SW_UP.2; also elsewhere on the board
P0.14: C31.2, R8.1, SW_ENT.2; also elsewhere on the board
P1.01: Q1.1 (G), R_PWR_EPD.1; also elsewhere on the board
P1.02: C29.2, R7.1, SW_DN.2; also elsewhere on the board
PREVGH: D5.1 (K), EPD_C9.2, J1.21
PREVGL: D2.2 (A), EPD_C11.2, J1.23
RESE: J1.3, Q3.2 (S), R1_EP_DR.2
SCK: J1.13; also elsewhere on the board
SCL: IC2.C1 (SCL), U3.7 (SCL); also elsewhere on the board
SDA: IC2.B2 (SDA), U3.8 (SDA); also elsewhere on the board
VBAT: C27.2, TP_VBAT.TP, U3.2 (CELL), U3.3 (VDD); also elsewhere on the board
VBUS: C42.2, C43.1, D3.5 (VBUS), J4.A4_B9 (VBUS), J4.A9_B4 (VBUS); also elsewhere on the board

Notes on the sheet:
E-Paper Display Connector
Fuel Gauge
USB C Connector & ESD
Protection
Haptic
Driver
Buttons
E-Paper Drive Circuit

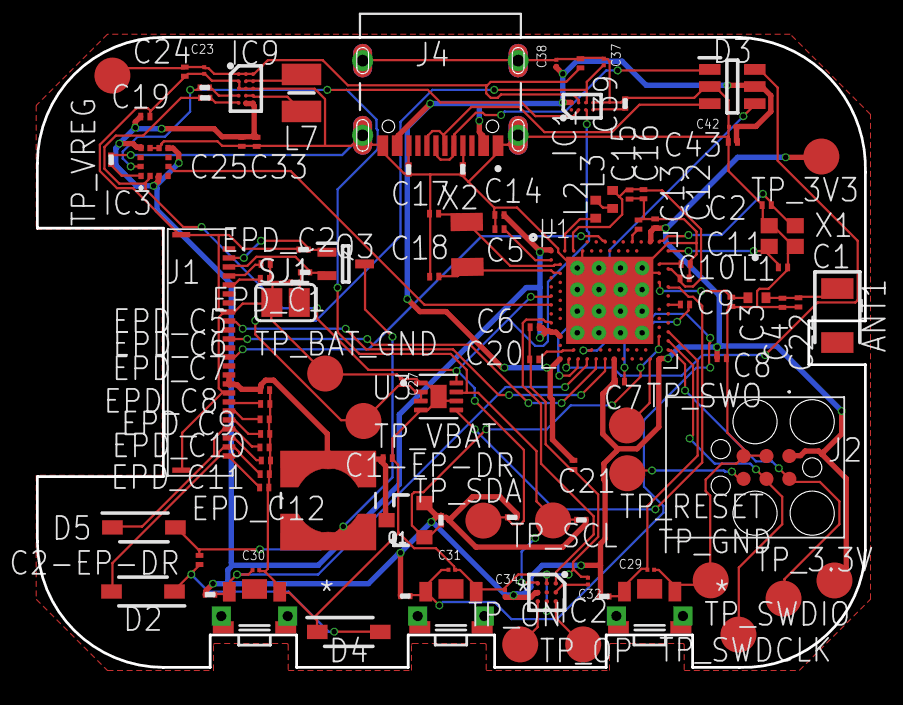
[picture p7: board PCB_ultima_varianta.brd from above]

Board: 2 copper layers, 46.0 x 35.0 mm, 105 parts (0 on the bottom side), 70 nets.

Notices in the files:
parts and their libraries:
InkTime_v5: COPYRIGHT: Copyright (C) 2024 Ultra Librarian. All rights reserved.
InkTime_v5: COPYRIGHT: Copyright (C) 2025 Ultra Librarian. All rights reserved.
